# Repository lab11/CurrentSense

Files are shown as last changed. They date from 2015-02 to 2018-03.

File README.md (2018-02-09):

CurrentSense
============

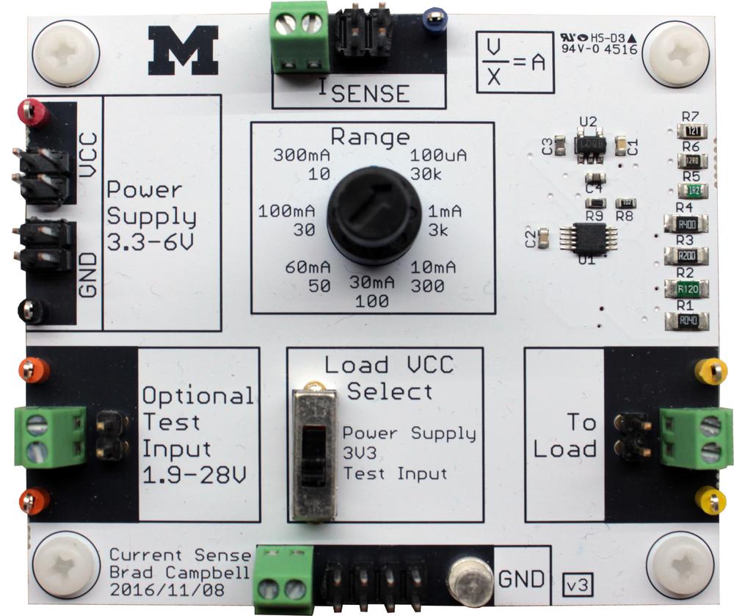
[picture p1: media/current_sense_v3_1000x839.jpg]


CurrentSense is a tool for measuring current in embedded systems.

Usage
-----

Description of the inputs:

- **Power Supply**: 3.3-6 volts that supplies power to the measurement circuitry.
- **Optional Test Input**: This input can be used to power the load under test.
This is particularly useful for energy-harvesting or other systems where the input
power is not stable.
- **I_Sense**: The measurable output signal that is proportional to current.
To calculate current, divide the I_Sense signal (in volts) by the number
that corresponds to the selected range value. This will return the current
in amps.
- **Range**: Select the maximum current you want to measure. Select this as
close to the maximum you wish to measure as possible.
- **Load VCC Select**: This selects how you would like to power the load under
test. The options
  - Power Supply: Use the input from the power supply that is powering the
  measurement circuitry to also power the load.
  - 3V3: Use the onboard regulated 3.3 V rail to power the load.
  - Test Input: Use the external test input to power the load.
- **To Load**: Connect to VCC or the signal you wish to measure.
- **GND**: A set of ground pins for convenience.

Errata
------

The 300 mA range doesn't seem to work on v3.

----

V2 Notes
--------

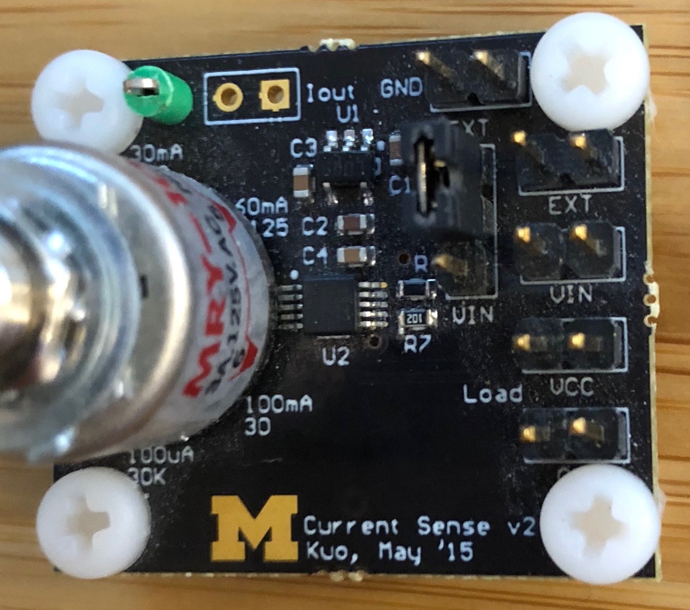
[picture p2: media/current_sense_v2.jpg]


You need a power selection jumper. You usually want to power the board externally,
in which case you'll want the jumper in the high position as pictured.

 - Connect external power (3.3-6V) to the EXT header at the top right.
   I usually also connect the external power to the GND header up here.
 - Connect the power supply for your target to VIN header.
 - Connect the VCC of your target to the VCC header
 - Connect the GND of your target to the GND header.
   I usually connect target GND to the GND header at the bottom, whose label is
   occluded by the screw.
 - Hook the scope probe to the test point at the top left (and GND anywhere)
 
The rest of the board is the same idea as above. Choose a range, measure voltage,
divide by the number on the board, get amperage.

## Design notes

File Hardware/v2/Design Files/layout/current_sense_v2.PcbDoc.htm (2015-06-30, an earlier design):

Reporting Options

# File in Previous Format

Date | : | 6/17/2015
Time | : | 3:51:51 PM
Filename | : | \\psf\Dropbox\Altium_YeSheng\current_sense\layout\current_sense_v2.PcbDoc

Version | Warning

This file was generated by an earlier version of the software

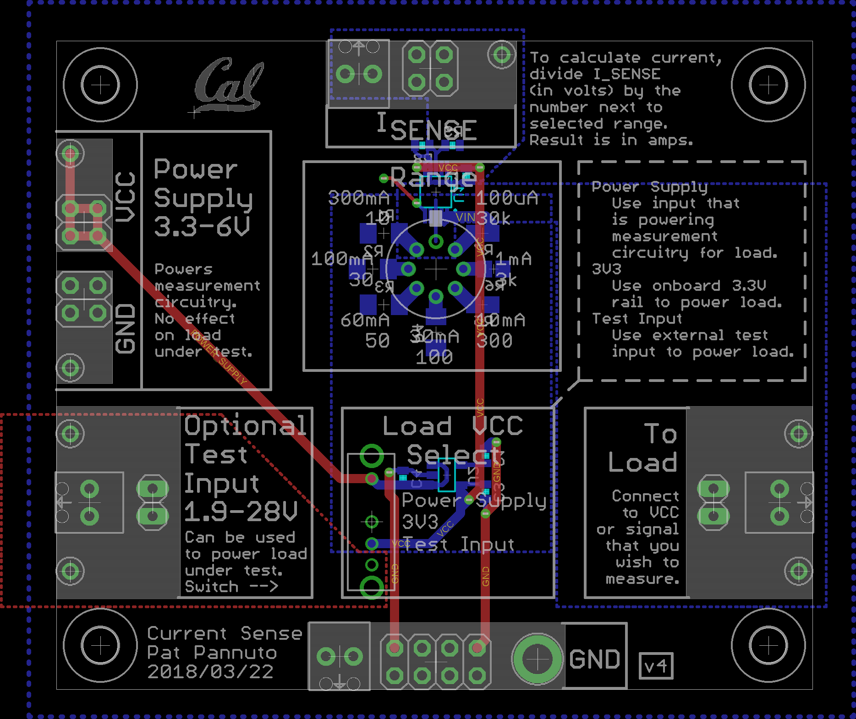
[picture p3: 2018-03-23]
Hardware/v4/current_sense_pcb.png

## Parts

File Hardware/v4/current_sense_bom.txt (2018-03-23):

# Bill of Materials
# Converted from current_sense_bom.xlsx
# Generated by bom_to_text.py
#
# # Bill of Materials                                                                                                                                                                                                                                 
# # Converted from {}                                                                                                                                                                                                                                 
# # Generated by bom_to_text.py                                                                                                                                                                                                                       
# #                                                                                                                                                                                                                                                   
#                                                                                                                                                                                                                                                     
# Qty                            Value                   Device                  Package            Parts                              Description                                                              DIGIKEY                  MOUSER       NEWARK
1                                0.01uF                  CAPACITOR0603_CAP       0603_CAP           C1                                 0402 Capacitor                                                           445-1304-1-ND                         
1                                0.1uF                   CAPACITOR0603_CAP       0603_CAP           C2                                 0402 Capacitor                                                           445-1316-1-ND                         
2                                1uF                     CAPACITOR0603_CAP       0603_CAP           C3, C4                             0402 Capacitor                                                           445-1604-1-ND                         
4                                SCREW-TERMINAL_2_0.100  SCREW-TERMINAL_2_0.100  CONN_BLOCK_2       J1, J2, J3, J4                     2x 0.100 in screw terminal block                                         277-1273-ND              651-1725656  71C4107
2                                                        PINHD-1X2               1X02               J5, J6                             PIN HEADER                                                                                                     
3                                                        PINHD-2X2               2X02               J7, J8, J9                         PIN HEADER                                                                                                     
1                                                        PINHD-2X4               2X04               J10                                PIN HEADER                                                                                                     
1                                0.04                    R-US_R1206              R1206              R1                                 RESISTOR, American symbol                                                311-.04LWCT-ND                        
1                                0.12                    R-US_R1206              R1206              R2                                 RESISTOR, American symbol                                                RL16R.12FCT-ND                        
1                                0.2                     R-US_R1206              R1206              R3                                 RESISTOR, American symbol                                                CSR1206FKR200CT-ND                    
1                                0.4                     R-US_R1206              R1206              R4                                 RESISTOR, American symbol                                                311-.4LWCT-ND                         
1                                1.2                     R-US_R0805              R0805              R5                                 RESISTOR, American symbol                                                RL12S1.2FCT-ND                        
1                                12                      R-US_R0805              R0805              R6                                 RESISTOR, American symbol                                                A103150CT-ND                          
1                                120                     R-US_R0805              R0805              R7                                 RESISTOR, American symbol                                                RG20N120WCT-ND                        
1                                1k                      RESISTOR0603_RES        0603-RES           R8                                 Resistor                                                                 P1.0KDBCT-ND                          
1                                249k                    RESISTOR0603_RES        0603-RES           R9                                 Resistor                                                                 P249KDBCT-ND                          
1                                RM107772BCB             RM107772BCB             RM-SWITCH          S1                                 Rotary Switch 8 Position SP7T 500mA (DC) 24VDC Through Hole              CKN10705-ND                           
1                                OS103011MS8QP1          OS103011MS8QP1          OS102011MS8QP1     S2                                 Slide Switch SP3T Through Hole                                           CKN9543-ND                            
7                                TEST_POINT_0.040IN      TEST_POINT_0.040IN      TESTPOINT_0.040IN  TP1, TP2, TP3, TP4, TP5, TP6, TP7  0.040in Test Point                                                       5001K-ND                              
1                                TEST_POINT_0.112IN      TEST_POINT_0.112IN      TESTPOINT_0.112IN  TP8                                Solder terminal, turreted                                                                                      40F6015
1                                MAX9922                 MAX9922                 UMAX10             U1                                 The MAX9922/MAX9923 ultra-precision, high-side current-                  MAX9922EUB+TCT-ND                     
1                                LP3985                  LP3985                  R-PDSO-G5          U2                                 Linear Voltage Regulator IC Positive Fixed 1 Output 3.3V 150mA SOT-23-5  LP3985IM5-3.3/NOPBCT-ND

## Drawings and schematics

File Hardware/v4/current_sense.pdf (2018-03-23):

# LDO

# Range Select

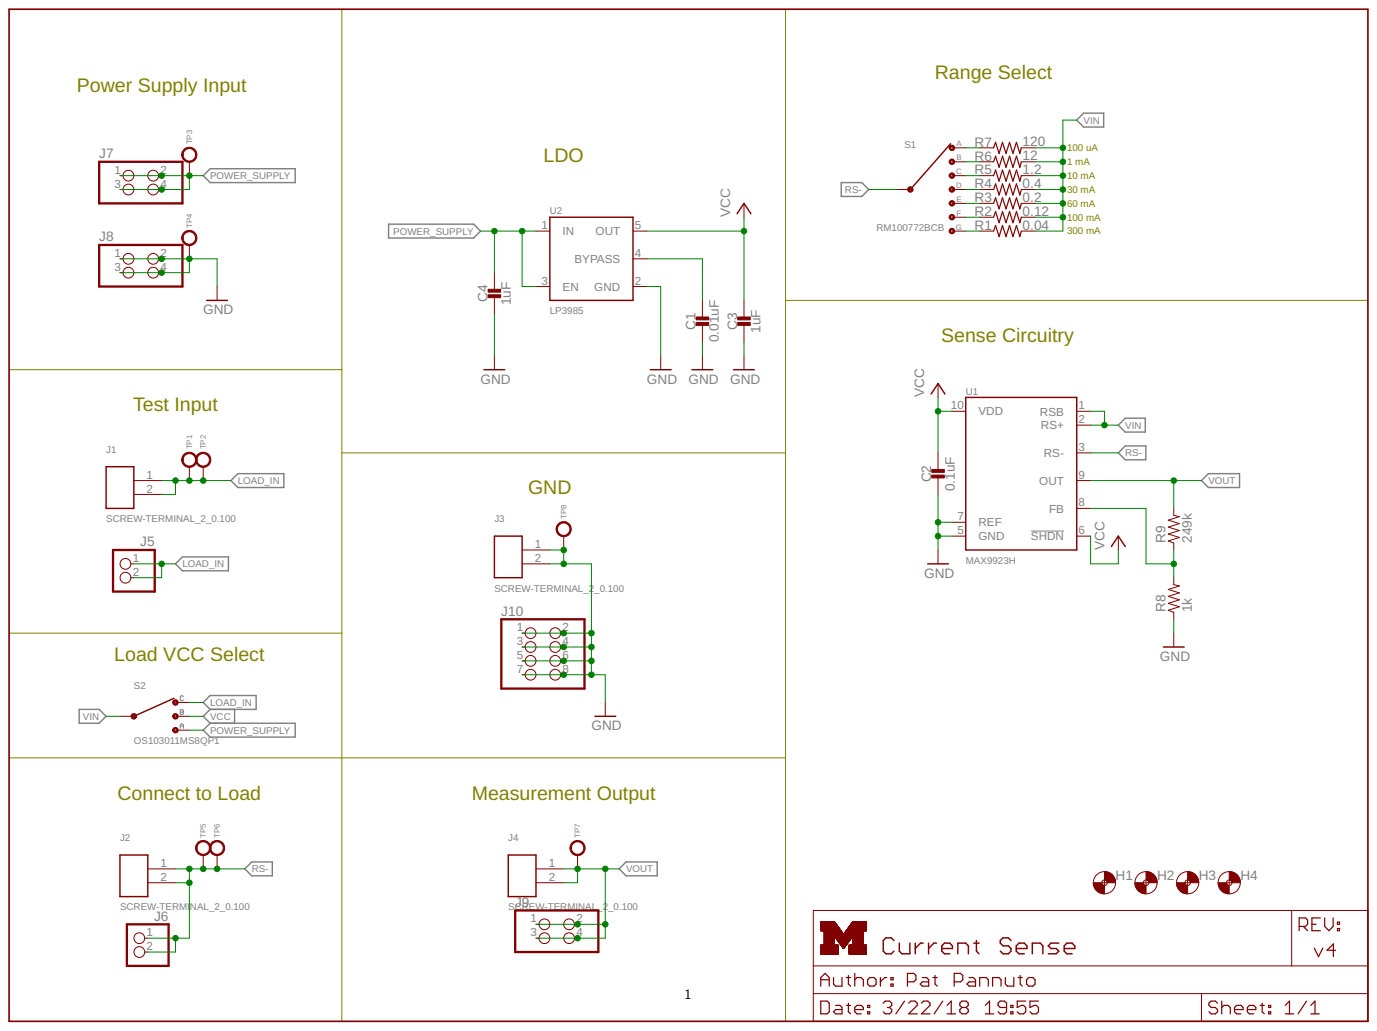
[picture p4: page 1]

100 uA Power Supply Input

## Top and Bottom Layers

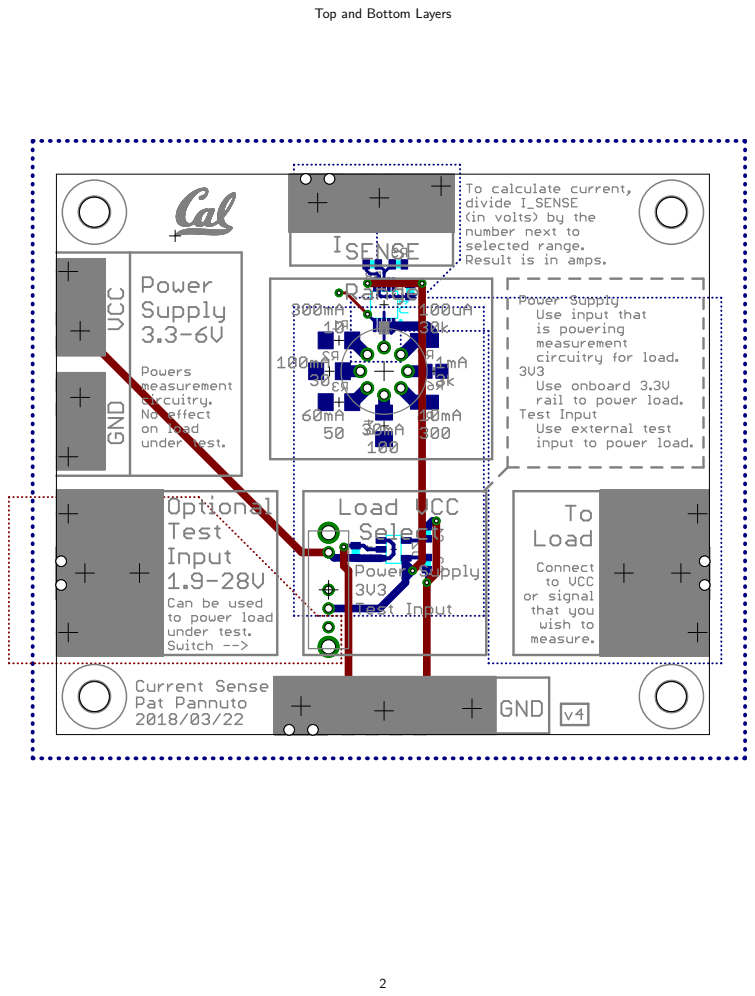
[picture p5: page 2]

## Top Layer

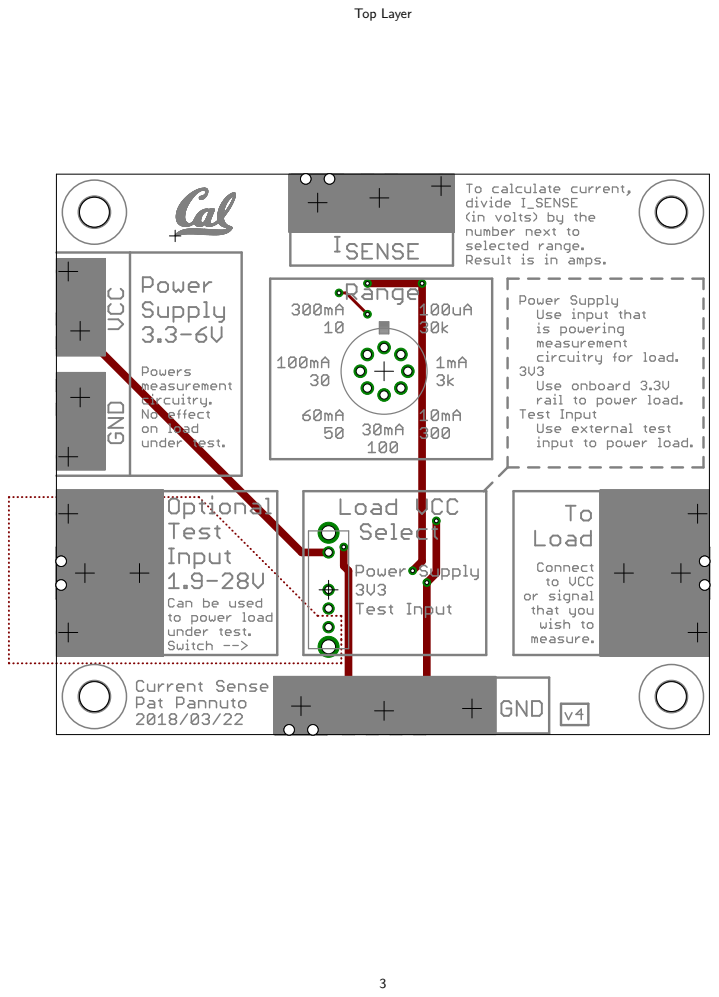
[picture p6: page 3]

## Bottom Layer

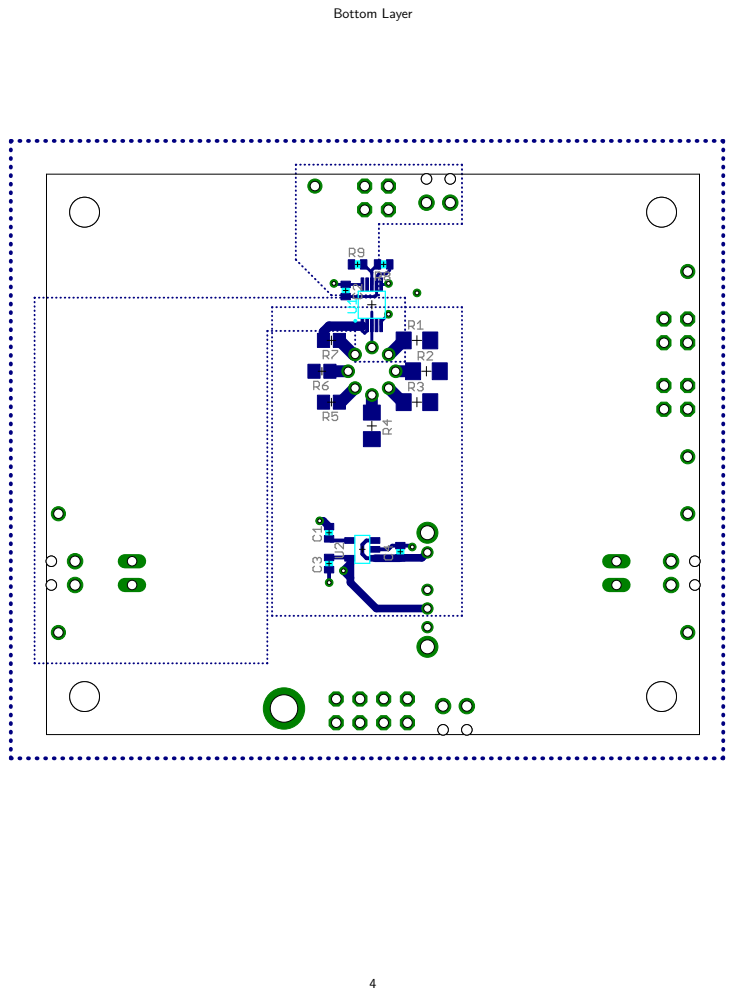
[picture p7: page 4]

## Top Copper Layer

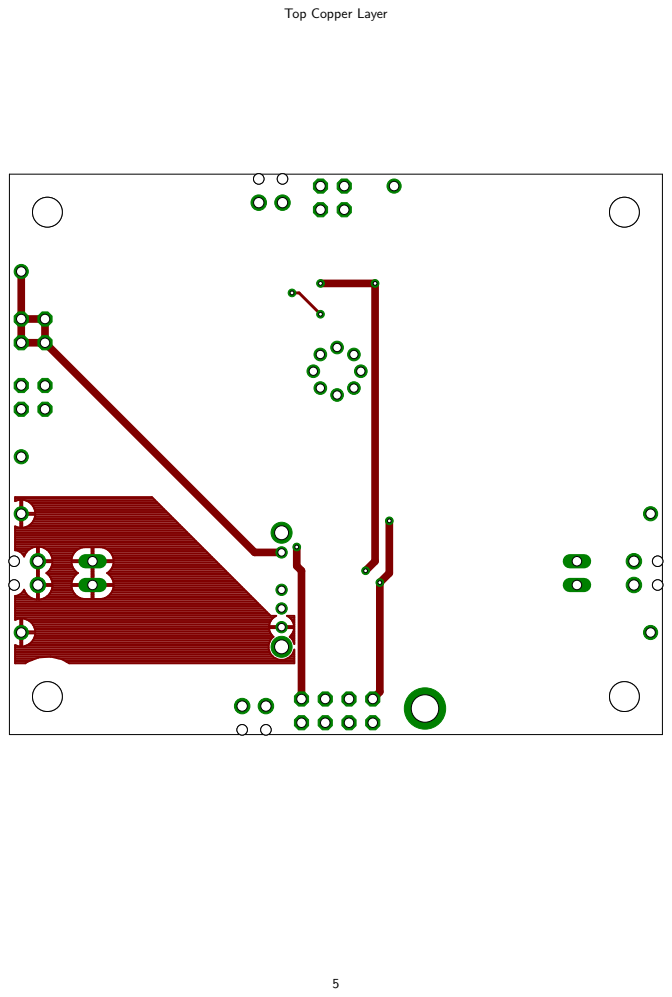
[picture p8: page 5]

## Bottom Copper Layer

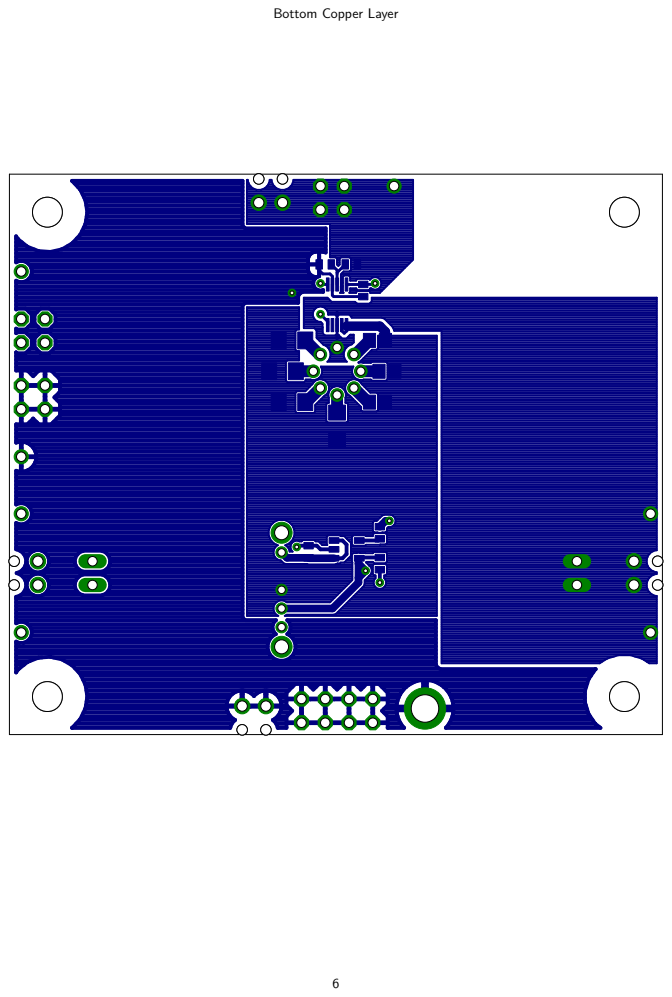
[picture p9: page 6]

## Top Paste Layer with Silkscreen

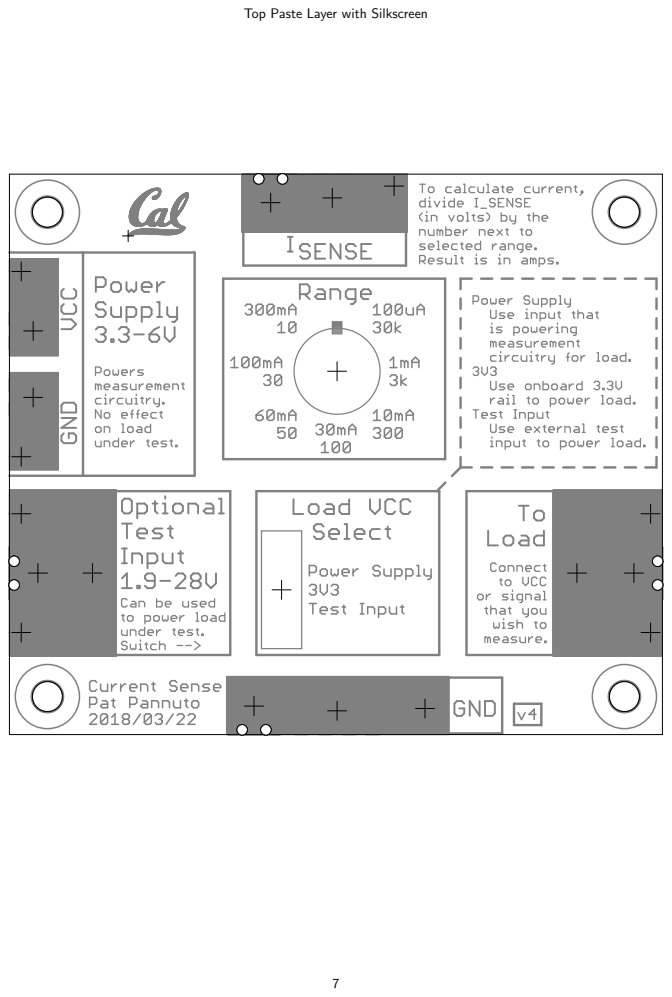
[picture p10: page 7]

## Bottom Paste Layer with Silkscreen

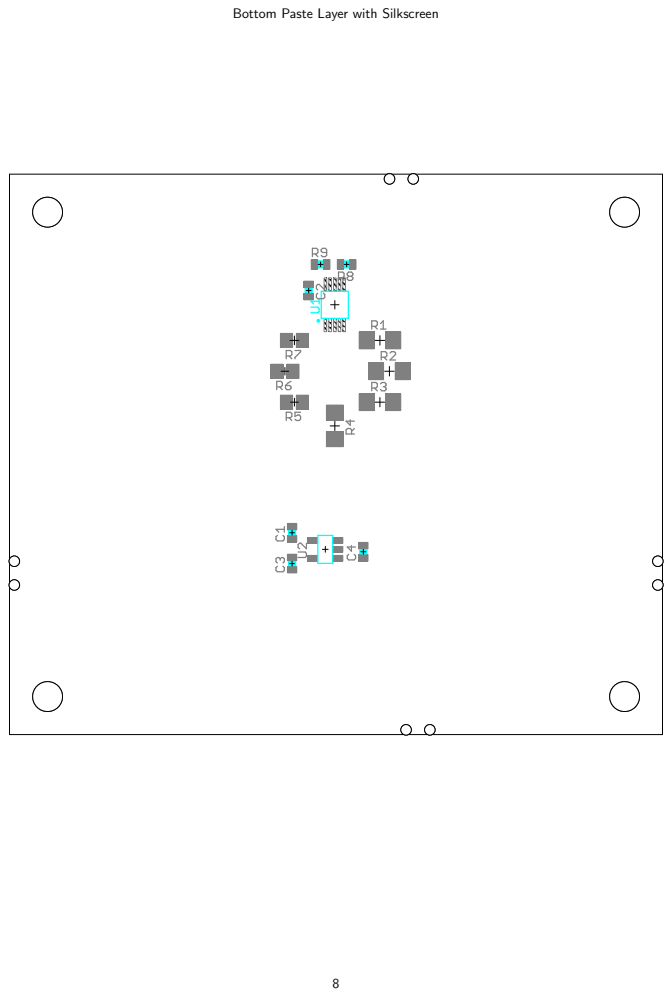
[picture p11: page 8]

## Top and Bottom Layers 1:1 Scale

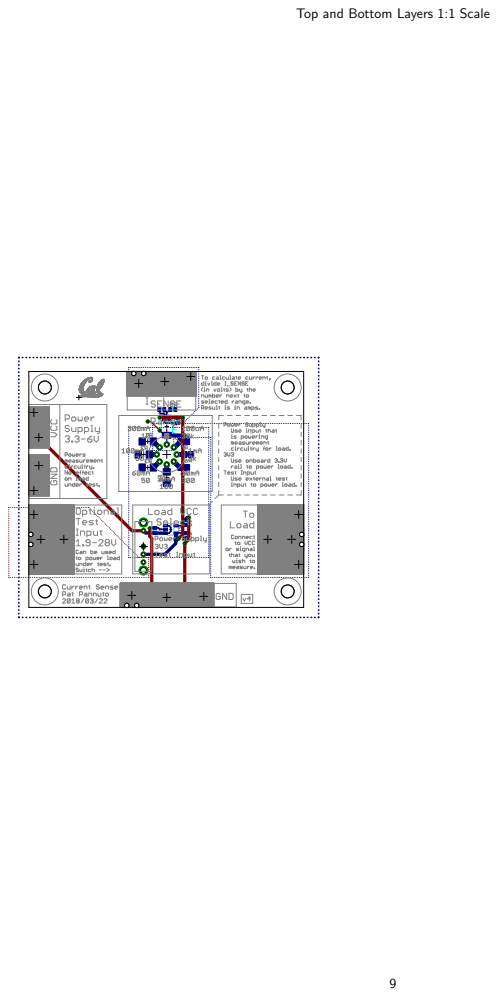
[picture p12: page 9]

## Top Layer 1:1 Scale

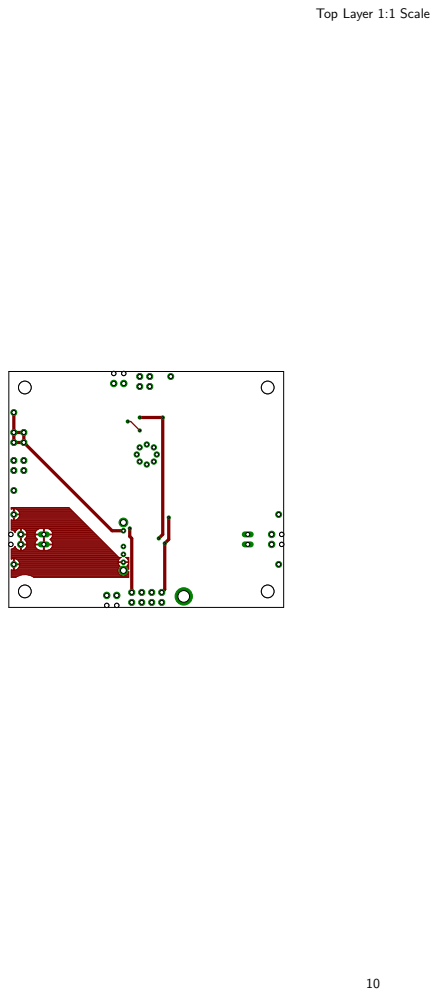
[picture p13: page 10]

## Bottom Copper Layer 1:1 Scale

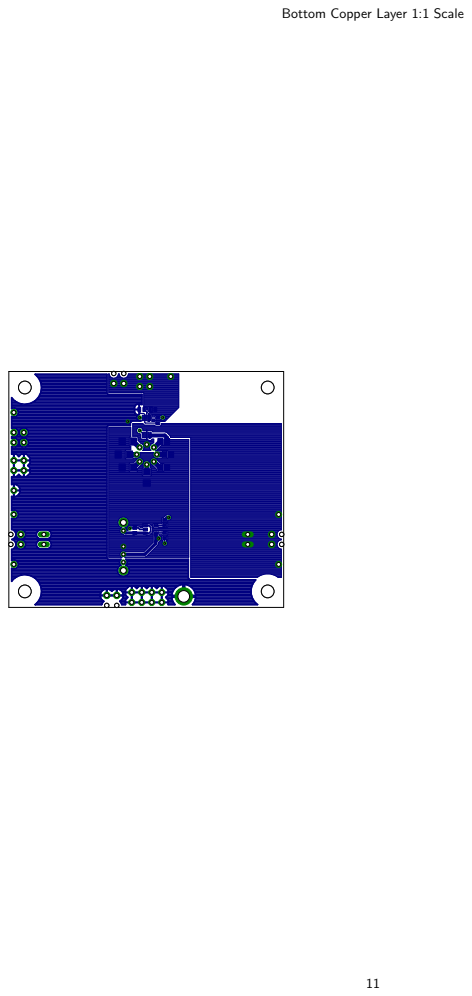
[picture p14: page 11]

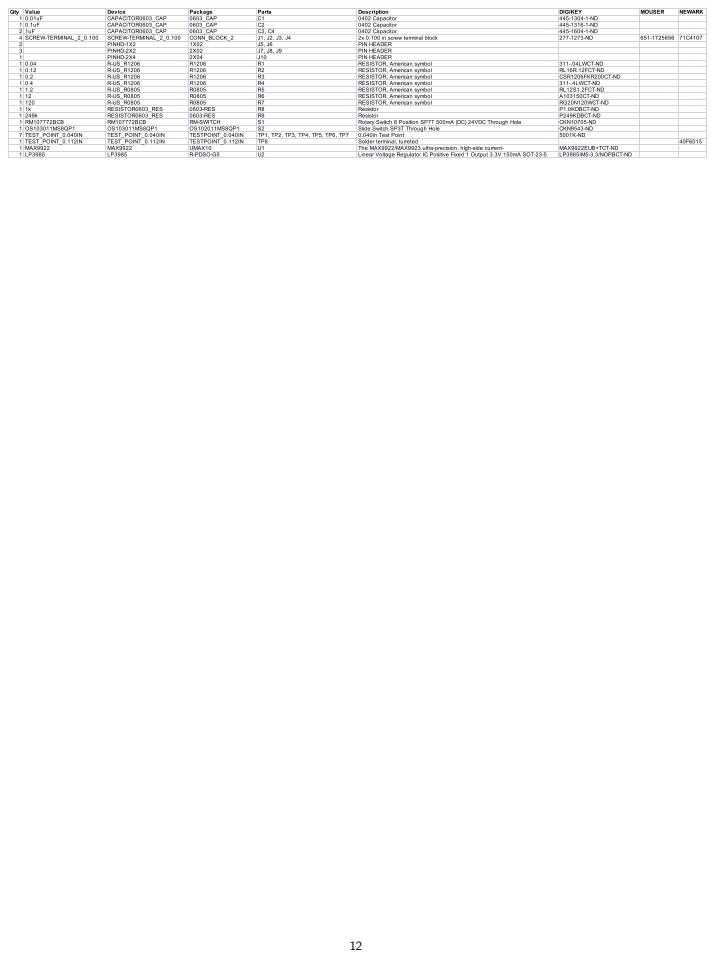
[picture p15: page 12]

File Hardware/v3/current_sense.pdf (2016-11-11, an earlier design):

## Power Supply Input

## LDO



Top and Bottom Layers

Top Layer

Bottom Layer


Top Copper Layer


Bottom Copper Layer


Top Paste Layer with Silkscreen

Bottom Paste Layer with Silkscreen


Top and Bottom Layers 1:1 Scale


Top Layer 1:1 Scale


Bottom Copper Layer 1:1 Scale

### current_sense

Qty Value | Device | Package
1 0.01uF | CAPACITOR0603_CAP | 0603_CAP
1 0.1uF | CAPACITOR0603_CAP | 0603_CAP
2 1uF | CAPACITOR0603_CAP | 0603_CAP
4 SCREW-TERMINAL_2_0.100 SCREW-TERMINAL_2_0.100 CONN_BLOCK_2
2 | PINHD-1X2 | 1X02
3 | PINHD-2X2 | 2X02
1 | PINHD-2X4 | 2X04
1 0.04 | R-US_R1206 | R1206
1 0.12 | R-US_R1206 | R1206
1 0.2 | R-US_R1206 | R1206
1 0.4 | R-US_R1206 | R1206
1 1.2 | R-US_R0805 | R0805
1 12 | R-US_R0805 | R0805
1 120 | R-US_R0805 | R0805
1 1k | RESISTOR0603_RES | 0603-RES
1 249k | RESISTOR0603_RES | 0603-RES
1 RM107772BCB | RM107772BCB | RM-SWITCH
1 OS103011MS8QP1 | OS103011MS8QP1 | OS102011MS8QP1
7 TEST_POINT_0.040IN | TEST_POINT_0.040IN | TESTPOINT_0.040IN
1 TEST_POINT_0.112IN | TEST_POINT_0.112IN | TESTPOINT_0.112IN
1 MAX9922 | MAX9922 | UMAX10
1 LP3985 | LP3985 | R-PDSO-G5

### current_sense

Parts
C1
C2
C3, C4
J1, J2, J3, J4
J5, J6
J7, J8, J9
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
TP1, TP2, TP3, TP4, TP5, TP6, TP7 TP8
U1
U2

### current_sense

Description | DIGIKEY
0402 Capacitor | 445-1304-1-ND
0402 Capacitor | 445-1316-1-ND
0402 Capacitor | 445-1604-1-ND
2x 0.100 in screw terminal block | 277-1273-ND
PIN HEADER
PIN HEADER
PIN HEADER
RESISTOR, American symbol | 311-.04LWCT-ND
RESISTOR, American symbol | RL16R.12FCT-ND
RESISTOR, American symbol | CSR1206FKR200CT-ND
RESISTOR, American symbol | 311-.4LWCT-ND
RESISTOR, American symbol | RL12S1.2FCT-ND
RESISTOR, American symbol | A103150CT-ND
RESISTOR, American symbol | RG20N120WCT-ND
Resistor | P1.0KDBCT-ND
Resistor | P249KDBCT-ND
Rotary Switch 8 Position SP7T 500mA (DC) 24VDC Through Hole | CKN10705-ND
Slide Switch SP3T Through Hole | CKN9543-ND
0.040in Test Point | 5001K-ND
Solder terminal, turreted
The MAX9922/MAX9923 ultra-precision, high-side current- | MAX9922EUB+TCT-ND
Linear Voltage Regulator IC Positive Fixed 1 Output 3.3V 150mA SOT-23-5 LP3985IM5-3.3/NOPBCT-ND

### current_sense

MOUSER NEWARK

651-1725656 71C4107

40F6015

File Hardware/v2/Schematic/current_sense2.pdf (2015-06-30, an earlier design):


Current Sense Title | University of Michigan

Author: Ye-Sheng Kuo | Revision: 2
Date: 6/30/2015 | Sheet * of *

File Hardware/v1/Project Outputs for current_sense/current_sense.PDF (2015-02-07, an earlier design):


* Title | Cannot open file C:\Users\samk uo\Dropbox\Al University of Michigan

Author: * | Revision: *
Date: 6/16/2014 | Sheet * of *






Designator | Description | Value | Quantity | Footprint
C1, C2 | Ceramic capacitor, 1 uF, 0603 package | 1 uF | 2 | 0603
C3 | Ceramic capacitor, 10000 pF, 0603 package | 10000 pF | 1 | 0603
C4 | Ceramic capacitor, 0.1 uF, 0603 package | 0.1 uF | 1 | 0603
C5 | Ceramic capacitor, 1000 pF, 0603 package | 1000 pF | 1 | 0603
J1 | TEST POINT PC MINI .040"D YELLOW | | 1 | TestPoint
P1, P2, P3, P4, P5 | 100 mils standard header | | 5 | 1x2 header
R1 | Resistor | 0.05 | 1 | C1206
R2 | Resistor | 0.1 | 1 | VCS1610
R3 | Resistor | 0.2 | 1 | CSM3637
R4 | Resistor | 1 | 1 | VCS1610
R5 | Resistor | 10 | 1 | 6-0805_N
R6 | Resistor | 300 | 1 | 6-0805_N
SW1 | SW ROTARY SP BLK KNOB 125V | | 1 | MRY switch
U1 | 150mA Low-Noise Ultra Low-Dropout CMOS Voltage Regulator | | 1 | SOT23-5
U2 | ultra-precision, high-side cur | | 1 | 10umax

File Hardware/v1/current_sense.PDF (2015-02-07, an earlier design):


* Title | Cannot open file C:\Users\samk uo\Dropbox\Al University of Michigan

Author: * | Revision: *
Date: 6/16/2014 | Sheet * of *






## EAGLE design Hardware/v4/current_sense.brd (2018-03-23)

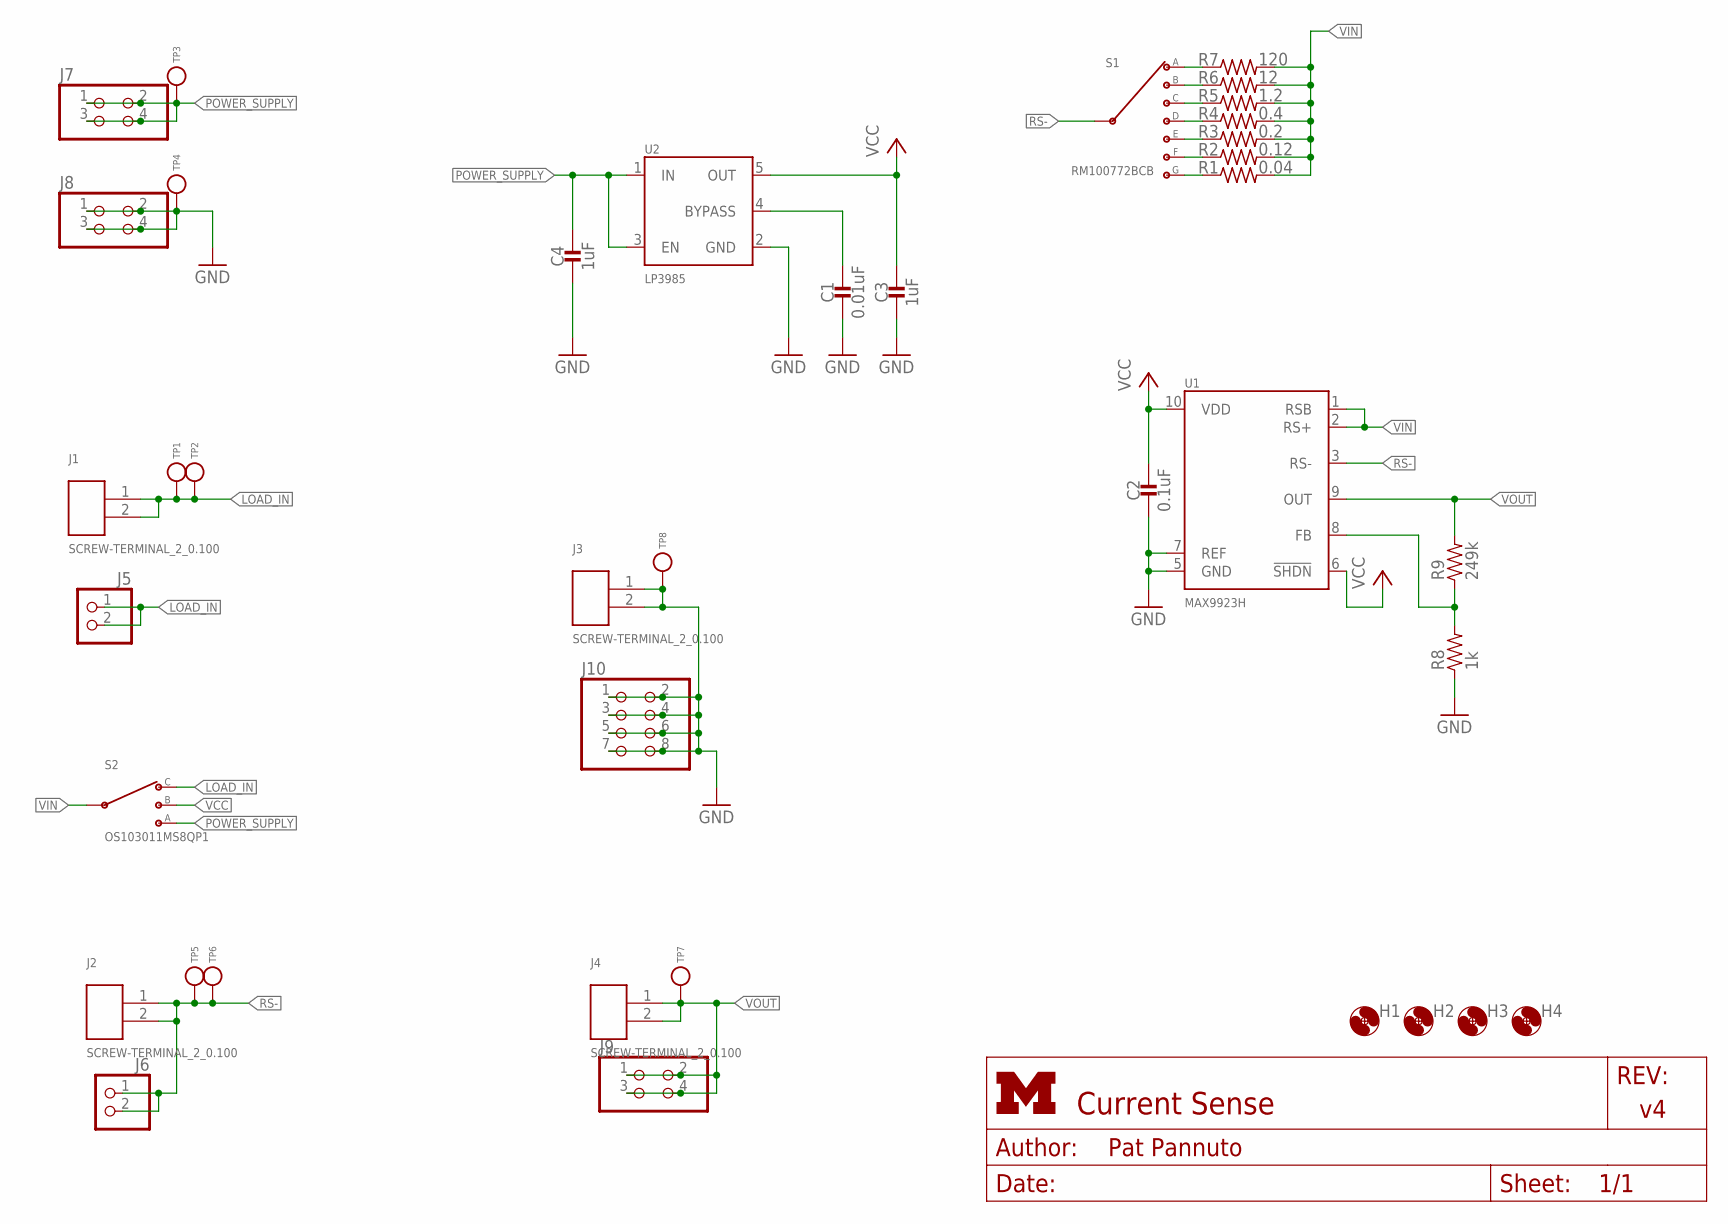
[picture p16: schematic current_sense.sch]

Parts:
C1: 0.01uF; 0603_CAP; MPN C1608X7R1E103K080AA; DIGIKEY 445-5100-1-ND
C2: 0.1uF; 0603_CAP; MPN C1608X7R1E104K080AA; DIGIKEY 445-1316-1-ND
C3, C4: 1uF; 0603_CAP; MPN C1608X7R1C105K080AC; DIGIKEY 445-1604-1-ND
H1, H2, H3, H4: MOUNT-HOLE3.2; 3,2
J1, J2, J3, J4: SCREW-TERMINAL_2_0.100; CONN_BLOCK_2
J5, J6: PINHD-1X2; 1X02
J7, J8, J9: PINHD-2X2; 2X02
J10: PINHD-2X4; 2X04
R1: 0.04; R1206; MPN RL1206FR-070R04L; DIGIKEY 311-.04LWCT-ND
R2: 0.12; R1206; MPN RL1632R-R120-F; DIGIKEY RL16R.12FCT-ND
R3: 0.2; R1206; MPN CSR1206FKR200; DIGIKEY CSR1206FKR200CT-ND
R4: 0.4; R1206; MPN RL1206FR-070R4L; DIGIKEY 311-.4LWCT-ND
R5: 1.2; R0805; MPN RL1220S-1R2-F; DIGIKEY RL12S1.2FCT-ND
R6: 12; R0805; MPN CPF0805B12RE1; DIGIKEY A103150CT-ND
R7: 120; R0805; MPN RG2012N-121-W-T1; DIGIKEY RG20N120WCT-ND
R8: 1k; 0603-RES; MPN ERA-3AEB102V; DIGIKEY P1.0KDBCT-ND
R9: 249k; 0603-RES; MPN ERA-3AEB2493V; DIGIKEY P249KDBCT-ND
S1: RM100772BCB; RM-SWITCH; MPN RM107772BCB; DIGIKEY CKN10705-ND
S2: OS103011MS8QP1; OS102011MS8QP1
TP1, TP2, TP3, TP4, TP5, TP6, TP7: TEST_POINT_0.040IN; TESTPOINT_0.040IN
TP8: TEST_POINT_0.112IN; TESTPOINT_0.112IN
U1: MAX9923H; UMAX10; MPN MAX9922EUB+T; DIGIKEY MAX9922EUB+TCT-ND
U2: LP3985; R-PDSO-G5

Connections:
GND: C1.2, C2.2, C3.2, C4.2, J3.1, J3.2, J8.1, J8.2, J8.3, J8.4, J10.1, J10.2, J10.3, J10.4, J10.5, J10.6, J10.7, J10.8, R8.1, TP4.TESTPOINT, TP8.1, U1.5 (GND), U1.7 (REF), U2.2 (GND)
LDO_BYPASS: C1.1, U2.4 (BYPASS)
LOAD_IN: J1.1, J1.2, J5.1, J5.2, S2.4 (3), TP1.TESTPOINT, TP2.TESTPOINT
POWER_SUPPLY: C4.1, J7.1, J7.2, J7.3, J7.4, S2.1, TP3.TESTPOINT, U2.1 (IN), U2.3 (EN)
RS-: J2.1, J2.2, J6.1, J6.2, S1.C (INPUT), TP5.TESTPOINT, TP6.TESTPOINT, U1.3 (RS-)
RS-_1MA: R6.1, S1.2 (B)
RS-_10MA: R5.1, S1.3 (C)
RS-_30MA: R4.1, S1.4 (D)
RS-_60MA: R3.1, S1.5 (E)
RS-_100MA: R2.1, S1.6 (F)
RS-_100UA: R7.1, S1.1 (A)
RS-_300MA: R1.1, S1.7 (G)
SENSE_FB: R8.2, R9.1, U1.8 (FB)
VCC: C2.1, C3.1, S2.3 (2), U1.6 (!SHDN), U1.10 (VDD), U2.5 (OUT)
VIN: R1.2, R2.2, R3.2, R4.2, R5.2, R6.2, R7.2, S2.2 (C), U1.1 (RSB), U1.2 (RS+)
VOUT: J4.1, J4.2, J9.1, J9.2, J9.3, J9.4, R9.2, TP7.TESTPOINT, U1.9 (OUT)

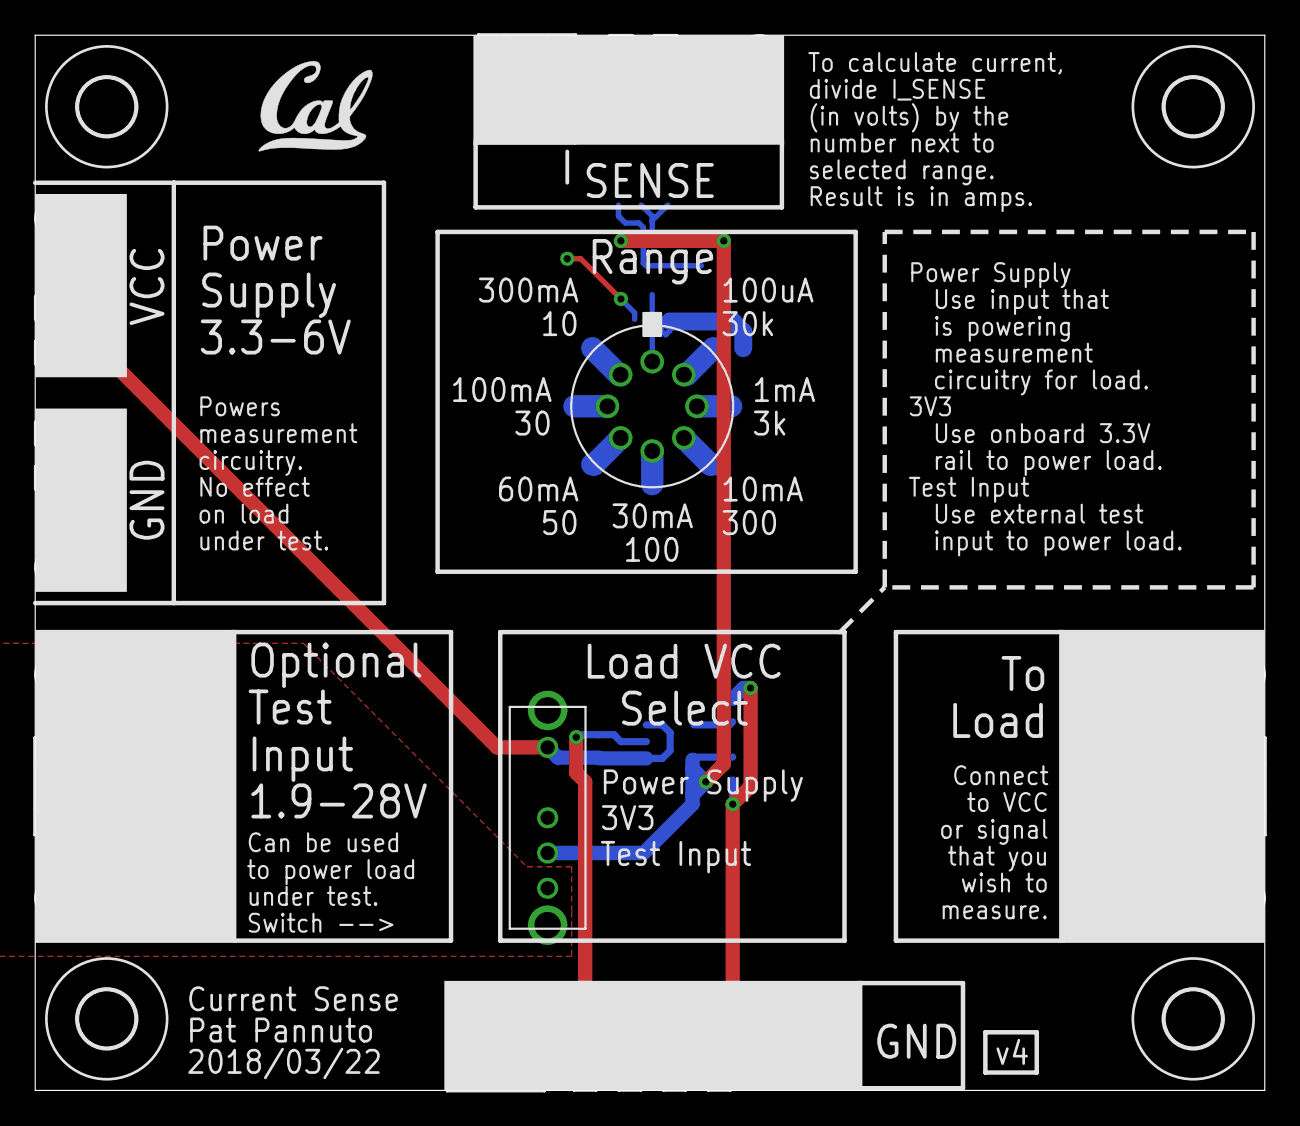
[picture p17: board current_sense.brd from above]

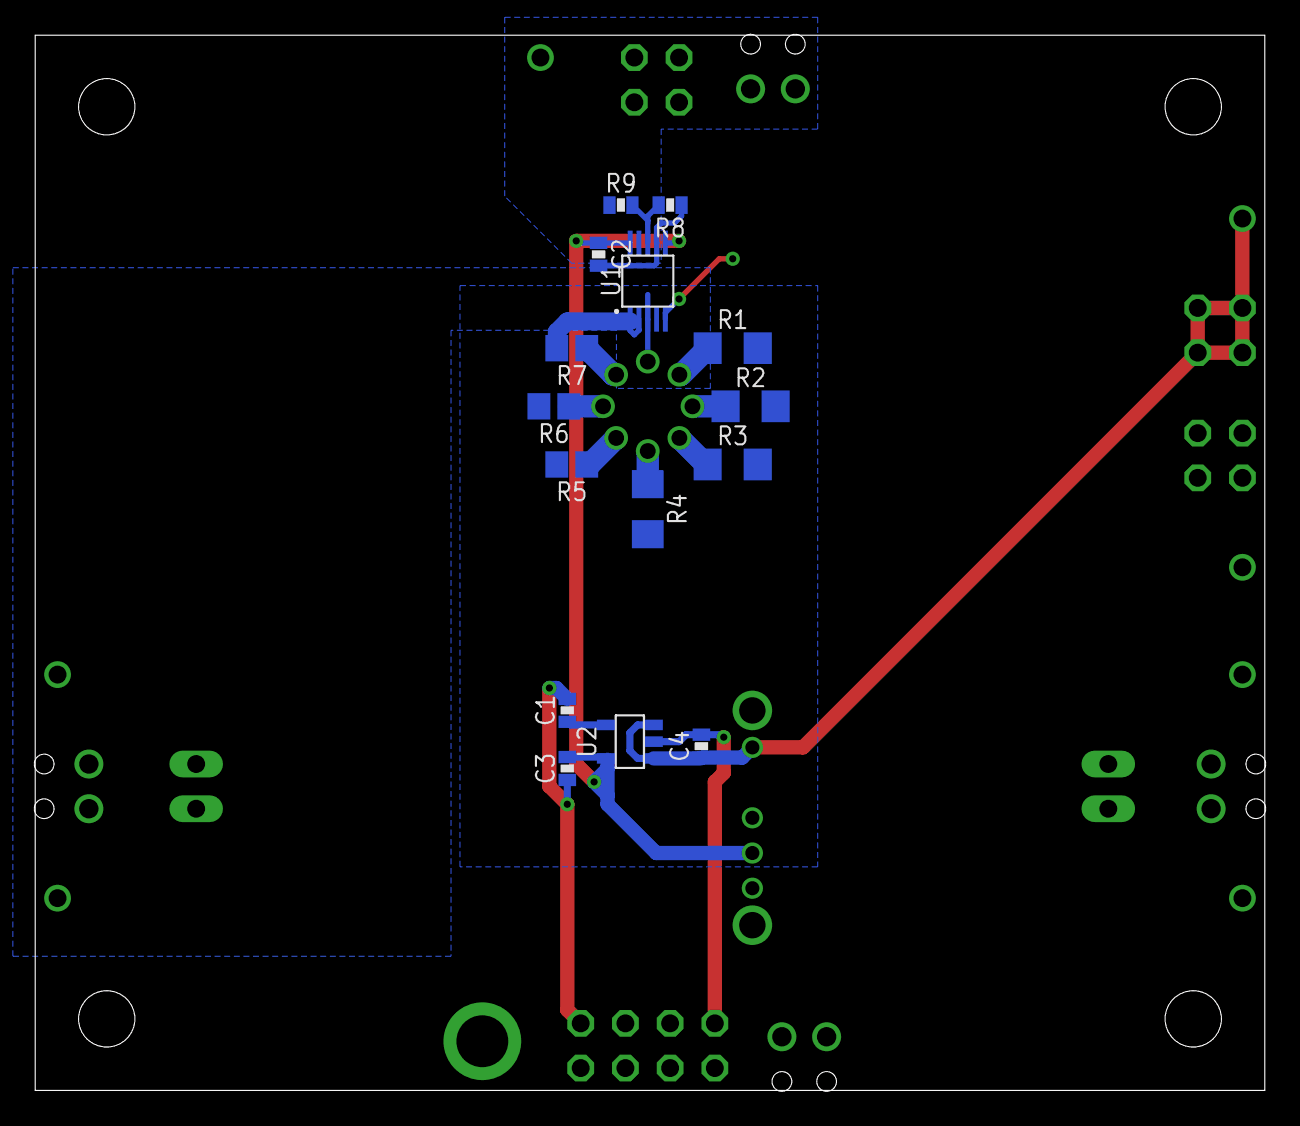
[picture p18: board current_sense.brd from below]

Board: 2 copper layers, 69.8 x 59.9 mm, 40 parts (15 on the bottom side), 16 nets.

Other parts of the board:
U$1: UCB_CAL_200MIL

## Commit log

2015-02-07 altium files
    [Bill of Materials-current_sense.xlsx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]
2015-06-30 add v2 hardware
    [current_sense.PrjPcb, current_sense.SchDoc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]
2016-11-09 start on rev 3
    [current_sense.brd, current_sense.sch]
2016-11-09 better silkscreen
    [current_sense.brd, current_sense.sch]
2016-11-09 renumbered parts and added bom
    [current_sense.brd, current_sense.sch, current_sense_bom.xlsx]
2016-11-11 updated current sense and zips
    [current_sense.brd, current_sense.sch, current_sense_bom.xlsx]
2018-02-09 Add pic of v2 board
2018-02-09 Add some directions for the v2 board
    Because I always forget
2018-03-22 add v4 (copy of v3)
    [current_sense.brd, current_sense.sch]
2018-03-22 Fix resistance issues, all doc on silk now
    [current_sense.brd, current_sense.sch]
2018-03-22 update global attrs
    [current_sense.sch]
2018-03-23 v4: fatten more traces because why not
    [current_sense.brd]
2018-03-23 v4: update attrs
    [current_sense.brd, current_sense.sch]
2018-03-23 v4: add hardware files
    [current_sense_bom.csv, current_sense_bom.xlsx]
